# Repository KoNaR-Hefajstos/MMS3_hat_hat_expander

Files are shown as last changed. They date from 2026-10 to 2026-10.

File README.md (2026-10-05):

# Hat hat expander

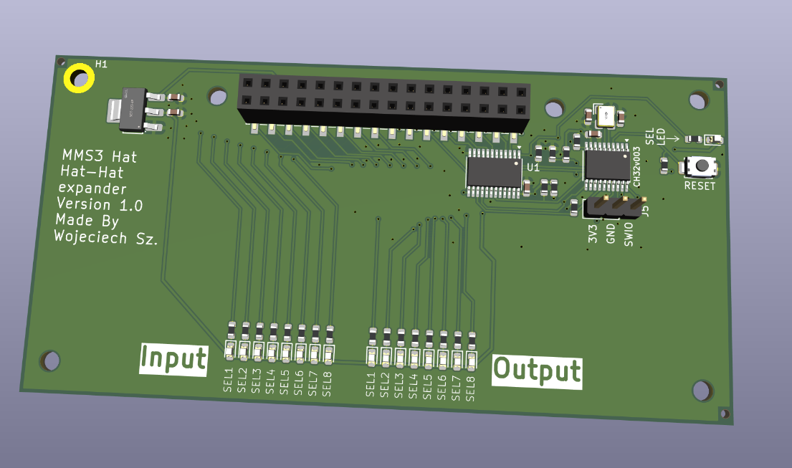
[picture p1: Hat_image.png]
zdjęcie hata


## Sekcja 0: Jak szybko, dobrze i tanio zrobić hata z dokumentacją

Szybka lista punkcików to wyklepania zanim hat magicznie się zrobi

1. **Sprawdź istniejące projekty:** Zobacz czy nie ma już jakiegoś hata który robi co potrzebujesz. Zobacz w forkach i poszukaj na githubie po hashtag'ach, jeśli nie to
2. **Utwórz Fork:** Kliknij przycisk **Fork** w prawym górnym rogu tego repozytorium.

1. **Konfiguracja repozytorium:** Daj mu adekwatną nazwe, i z'clone'uj forka do siebie na pc
2. **Zasady projektowania:**
   * Dokładniejsza dokumentacja znajduje się w Sekcji 2.
   * Do komunikacji możesz używać **wyłącznie** interfejsów: **I2C, SPI oraz UART**.
   * Modyfikuj połączeń złącza chainbus, bus switch'a i EEPROM'a
   * Nie modyfikuj zarysu płytki, otworów montażowych ani pozycji złączy ChainBus.
   * Możesz usunąć złącze XT60, jeśli Twój projekt go nie wymaga.

### Checklista przed zakończeniem projektu
Przed oznaczeniem projektu jako gotowy i wykonaniem ostatecznego commita, upewnij się, że zrealizowałeś poniższe punkty:

- [ ] Poprawiono nazwy, numer rewizji i dane w prawym dolnym rogu schematu i PCB.
- [ ] Dodano podpis autora/autorów oraz aktualny numer wersji na PCB.
- [ ] Zaktualizowano readme (usunąć tą sekcje)
- [ ] Zaktualizowano opis repo żeby opisywał krótko co robi PCB i jakie ma arkusze hierarchiczne do użycia w nowych hat'ach
- [ ] Usunięto z repozytorium zdjęcia z template'a.
- [ ] Wybrano i zaktualizowano licencję projektu **Uwaga: Wstpęnie już są użyte licencje**.
- [ ] Wygenerowano pliki produkcyjne Gerber
- [ ] Zrobiono commit'a i push'a

### Licencja
Co do licencji, wstępnie jest użyta
* Dla template'a - CC0 1.0 Universal  -> Róbcie co chcecie: Zmieniajce, usuńcie mój podpis, zróbcie closed source. Mi jest to obojętne
* PCB - CERN-OHL-W -> Ktoś może to modyfikować i sprzedać, ale musi zostawić projekt open source i ciebie jako twórce
* Software - MIT License -> Ktoś może to modyfikować i sprzedać, musi odnotować ciebie jako twórce ale **NIE MUSI ZOSTAWIĆ OPEN SOURCE**

Jeśli je modyfikujesz, pamiętaj usunać treści starych licencji

---

## Sekcja 1: Dokumentacja Hat'a

### Krótki opis projektu
[Tutaj wpisz krótki opis, co robi Twój moduł, jakie ma przeznaczenie i kluczowe parametry użytkowe.]

### Zgodność ze standardem ChainBus

* ✅ / ❌ Używa złącza ChainBus, nie zmienia jego miejsca ani pinoutu.
* ✅ / ❌ Używa wyłącznie interfejsów I2C, SPI lub UART i nie inicjuje samodzielnie nowych transmisji (Nie jest master'em I2C albo SPI).
* ✅ / ❌ Spełnia wymagania mechaniczne standardu (wymiary PCB, rozstaw otworów).
* ✅ / ❌ Pobiera maksymalny prąd zgodny z ilością na jednego hat'a
* ✅ / ❌ Obsługuje napięcie wejściowe BRD_VIN do wartości 48V.
<!-- Usuń odpowiednie emoji. Wszystkie powinny być na zielono. Jeśli z czymś nie jest zgodny to napisz w jaki sposób -->

### Komunikacja i adresowanie

#### Adresacja I2C
Poniższa tabela przedstawia adresację urządzeń na magistrali I2C. Wszystkie adresy podane są w formacie 7-bitowym.

| Układ (IC) | Funkcja |  Address |
| :--- | :--- | :---: |
| **JP3721** | Sterownik piekarnika | `1010000b` |
| **PCAL9535A** | Ekspander GPIO (Dioda LED, Krańcówki) | `0100000b` |
| **TMP102** | Czujnik temperatury | `1001000b` |

#### Magistrala SPI
Urządzenia SPI podłączone są bezpośrednio do magistrali systemowej bez użycia dodatkowych multiplekserów.

| Układ (IC)  | Funkcja | chainbus/multiplexer |
| :--- | :--- | :---: |
| **TMC5160** | Sterownik silnika krokowego | `chainbus` |

#### Magistrala UART
Komunikacja szeregowa UART realizowana jest w sposób bezpośredni z układem docelowym.

| Układ (IC) | Funkcja | chainbus/multiplexer |
| :--- | :--- | :---: |
| **ESP32-C3** | Adapter WI-FI | `chainbus` |

### Pinout złączy

| Jn | Co | Jaki pin co robi |
| :----- | :--- | :--- |
| **J1** | Zasilanie zewnętrzne silników | Pin 1: VIN (zasilanie dodatnie)<br>Pin 2: GND (masa zasilania) |
| **J2** | Wyjście faz silnika krokowego | Pin 1: Faza A1<br>Pin 2: Faza A2<br>Pin 3: Faza B1<br>Pin 4: Faza B2 |
| **J3** | Wejście czujnika krańcowego (Limit Switch) | Pin 1: Sygnał wejściowy (z rezystorem Pull-Up)<br>Pin 2: GND (masa)  |

### Konfiguracja układu (Zworki/Rezystory)

| Co | Jak podłączone | Efekt |
| :--- | :--- | :--- |
| **J1** | 1-2 zwarte | Silnik DC |
| | rozwarte | Silnik BLDC |
| **J2** | 1-2 zwarte | 3.3V out |
| | 2-3 zwarte | 5V out |
| **R1, R2, R3** | Wlutowany R1 | 3.3V out |
| | Wlutowany R2 | 5V out |
| | Wlutowany R3 | VIN out |

### Szczegółowy opis techniczny
[Tutaj umieść opis działania układu, parametry maksymalne etc]

### Gotowe arkusze hierarchiczne
W projekcie zaprojektowano/użyto następujących arkuszy hierarchicznych:
* [Nazwa arkusza 1] – [Krótki opis funkcjonalności, np. Zasilacz impulsowy 5V] - [ oryginalny/ wzięty z hata XXX]
* [Nazwa arkusza 2] – [Krótki opis] - [ -||- ]

---

## Sekcja 2: Specyfikacja standardu ChainBus

### Architektura i łączenie modułów
Standard ChainBus umożliwia modułowe łączenie hatów. Na jednym MMS3 można zamontować pionowo **do 8 hat'ów**. Połączenie realizowane jest poprzez wpięcie złącza męskiego kolejnego hat'a w złącze żeńskie poprzedniego

### Komunikacja i sterowanie
Magistrala ChainBus jest w pełni cyfrowa. Płyta główna nie steruje bezpośrednio sygnałami ogólnego przeznaczenia (GPIO) na poszczególnych hat'ach. Wszelkie operacje (np. obsługa diod LED, odczyt krańcówek, generowanie sygnałów PWM) muszą być realizowane przez dedykowane układy scalone (np. ekspandery portów, sterowniki) komunikujące się przez interfejsy systemowe.

*Przykład:*
`MCU` $\rightarrow$ `Expander GPIO po I2C` $\rightarrow$ `Dioda LED`

Wybór aktywnego modułu realizowany jest przez układ przełącznika magistrali (bus switch) na płycie głównej. Dzięki temu linie I2C, SPI i UART są niezależne dla każdego hat'a (brak konfliktów adresów I2C między różnymi hatami).
* **Identyfikacja:** Każdy moduł powinien posiadać pamięć EEPROM na magistrali I2C w celu identyfikacji płyty przez system - układ M24C64-W skonfigurowany na adres `1010000` przy liniach adresowych A0, A1, A2 zwartych do masy.

### Zasilanie
Złącze ChainBus dostarcza następujące linie zasilania:

| Magistrala zasilania | Napięcie znamionowe | Maksymalny prąd (łączny dla 8 hatów) | Szacowany prąd na jeden hat |
| :--- | :---: | :---: | :---: |
| **5V** | 5.0 V | 1.0 A | 125 mA |
| **12V stby** | 12.0 V | 0.5 A | 65 mA |
| **BRD_VIN** | 12.0 V – 48.0 V | 1.5 A | 185 mA |

*   Komponenty podłączone do linii `BRD_VIN` muszą być przystosowane do pracy z napięciem od 12V do **48 V**.
*   W przypadku zapotrzebowania na wyższą moc, dopuszczalne jest zastosowanie dodatkowego złącza zasilania XT60 (obciążalność do ok. 60 A).

### Wymagania mechaniczne i złącza
* **Wymiary PCB:** Niedozwolona jest zmiana obrysu płytki oraz położenia otworów montażowych, aby zachować kompatybilność mechaniczną.
* **Pozycjonowanie złączy ChainBus:** Położenie złącza standardu 2x16 SMD (raster 2.54 mm) musi być zgodne z szablonem. Złącze żeńskie montowane jest na stronie FRONT, natomiast złącze męskie na stronie BACK.
* **Interfejsy zewnętrzne:** Złącza wejścia/wyjścia (domyślnie standard JST-XH 2.5 mm o obciążalności do 3 A) oraz opcjonalne złącze XT60 powinny być umieszczone przy dolnej krawędzi płytki. Elementy regulacyjne i sygnalizacyjne (potencjometry, przełączniki, diody LED) należy lokalizować przy prawej krawędzi płytki.
* **Komponenty** Wszystkie komponenty powinny być na stronie front płytki żeby nie haczyły o elementy ze wcześniejszego hat'a

---

## Sekcja 3: Licencja, linki i tagi

### Licencjonowanie projektu

*   **PCB:** [CERN-OHL-W](https://ohwr.org/project/cernohl/wikis/Documents/CERN-OHL-version-2) - Umożliwia modyfikacje i sprzedaż, ale musi pozostawić oryginalnego autora i zmiany muszą być open source
*   **Software:** [MIT License](https://opensource.org/licenses/MIT) - Umożliwia modyfikacje i sprzedaż, ale musi pozostawić oryginalnego autora. Zmiany **nie muszą być open source**

[Template](https://github.com/KoNaR-Hefajstos/MMS3_hat_templates/) jest na licencji CC0 1.0 Universal. **Reszta projektu nie jest na tej licencji**
### Tagi projektu
#chainbus #MMS3 #ModuCard

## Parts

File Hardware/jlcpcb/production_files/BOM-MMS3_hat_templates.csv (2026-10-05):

Comment | Designator | Footprint | LCSC | Quantity
100nF | C1,C3 | C_0603 | C14663 | 2
10kΩ | R1,R10,R2,R3,R4,R6,R9 | R_0603 | C25804 | 7
10uF | C16,C18 | C_0603 | C19702 | 2
12pF | C4,C5 | C_0603 | C38523 | 2
1kΩ | R12,R15,R16,R17,R18,R19,R20,R21,R22,R23,R24,R25,R26,R27,R28,R29,R7 | R_0603 | C21190 | 17
AMS1117 | U4 | SOT-223-3_L6.5-W3.4-P2.30-LS7.0-BR | C6186 | 1
Red | D10,D11,D12,D13,D14,D15,D16,D17,D18,D2,D3,D4,D5,D6,D7,D8,D9 | D_0603 | C2286 | 17
SN74CB3Q3384APW | U1 | TSSOP-24_4.4x7.8mm_P0.65mm | C469874 | 1
Tactile Button, 160gf | S1 | SW_TS-1088-AR02016 | C720477 | 1
X322525MOB4SI | X1 | OSC-SMD_4P-L3.2-W2.5-BL | C9006 | 1
CH32V003FxPx | U3 | TSSOP-20_4.4x6.5mm_P0.65mm |  | 1
Chainbus Out | J2 | PinSocket_2x16_P2.54mm_Vertical_SMD |  | 1
~ | H8 | Hole_Tooling_JLCPCB |  | 1
~ | H7 | Hole_Tooling_JLCPCB |  | 1
~ | H9 | Hole_Tooling_JLCPCB |  | 1
Program | J5 | PinHeader_1x03_P2.54mm_Vertical |  | 1
Chainbus in | J1 | PinHeader_2x16_P2.54mm_Vertical_SMD |  | 1

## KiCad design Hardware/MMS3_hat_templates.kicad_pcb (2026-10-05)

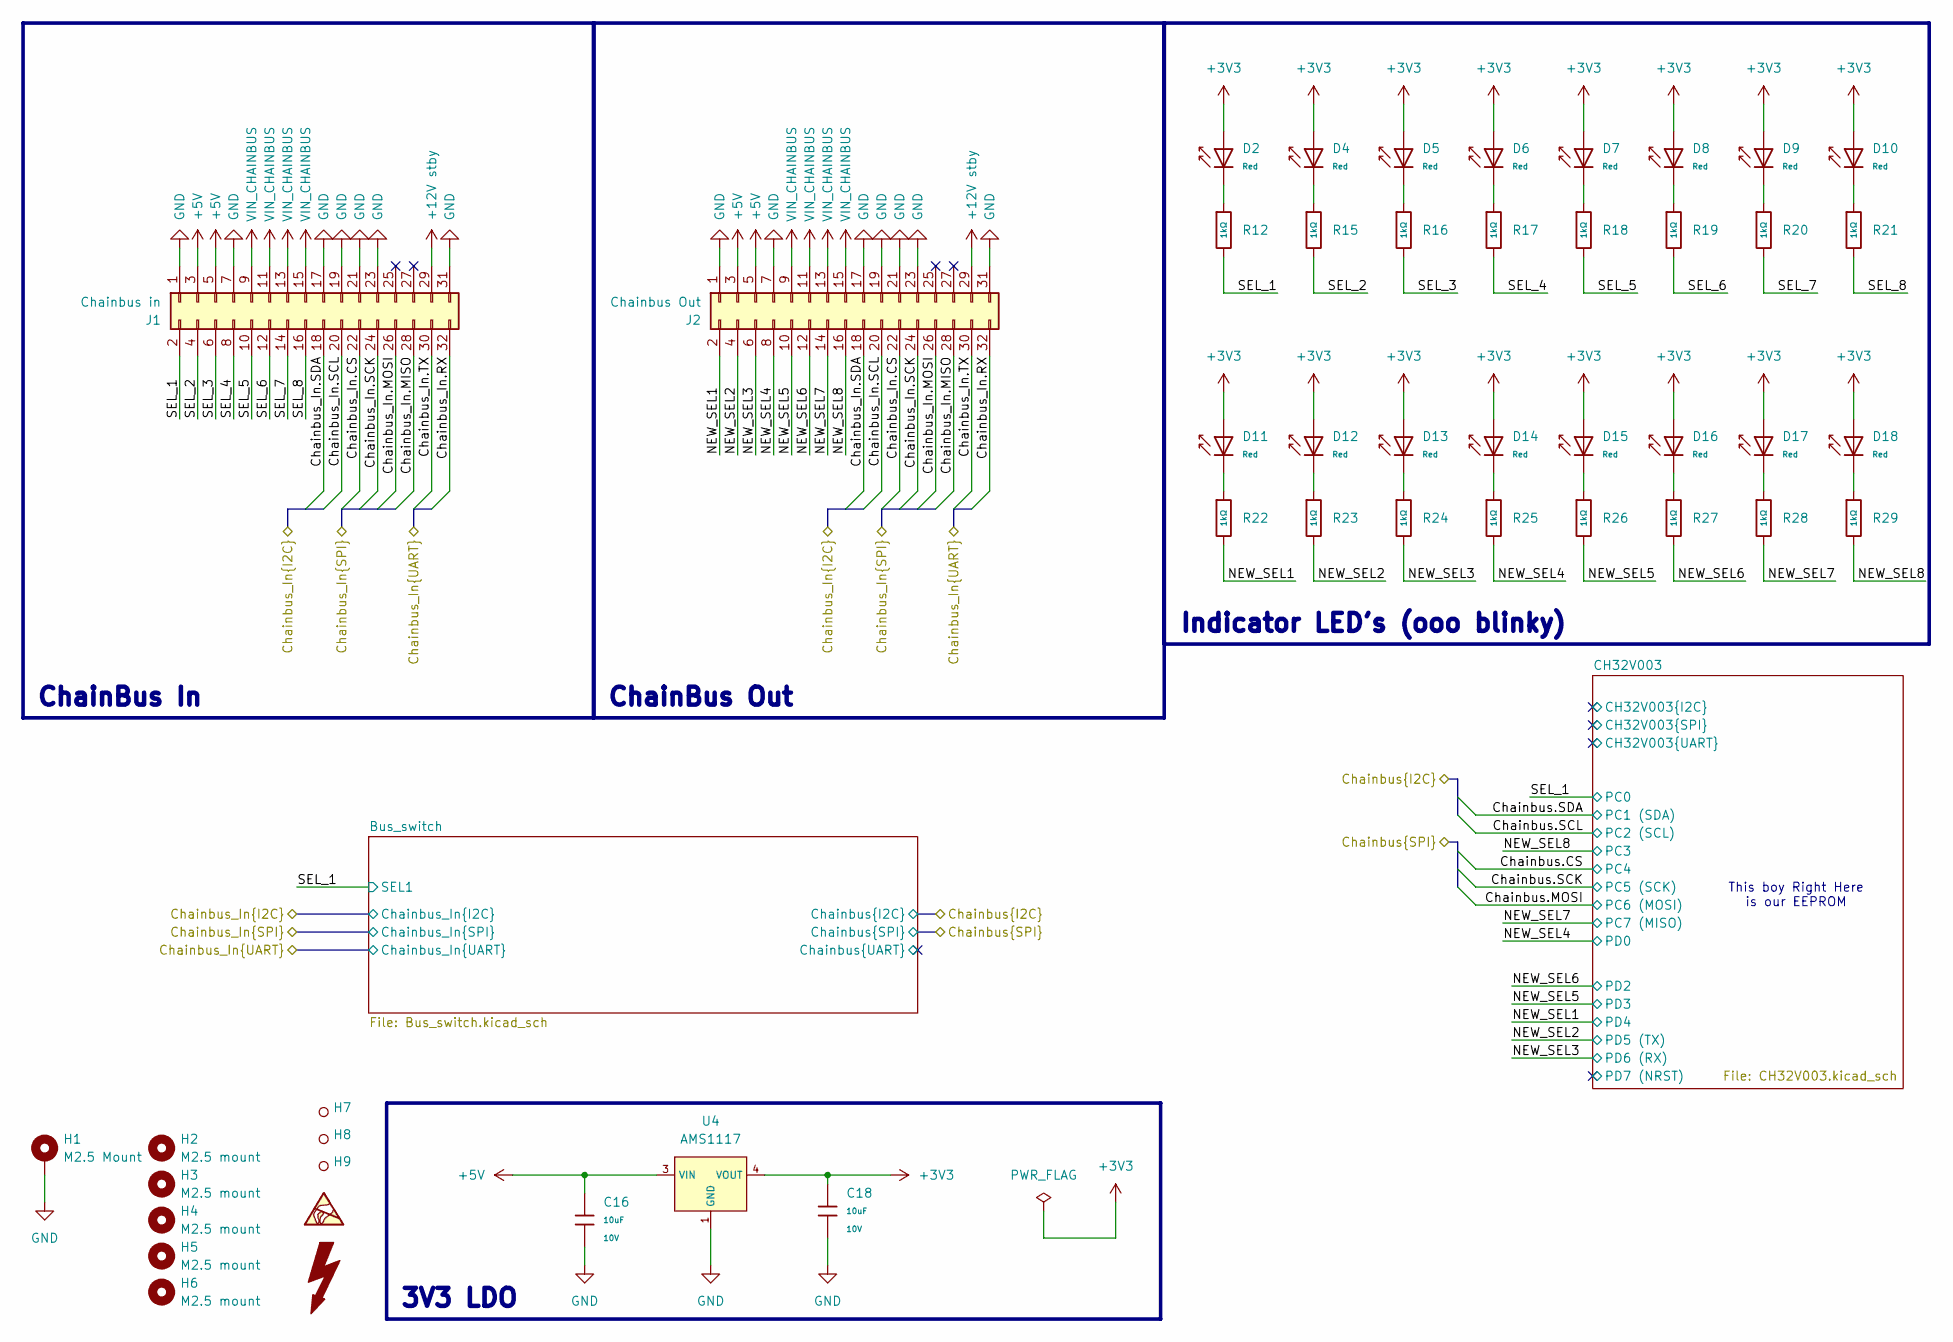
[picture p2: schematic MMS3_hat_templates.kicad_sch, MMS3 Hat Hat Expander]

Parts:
C16, C18: 10uF; C_0603; Voltage Rated 10V; Tolerance ±10%; Part CL10A106KP8NNNC; LCSC C19702
D2, D4, D5, D6, D7, D8, D9, D10, D11, D12, D13, D14, D15, D16, D17, D18: Red; D_0603; Part KT-0603R; LCSC C2286
H1: M2.5 Mount; MountingHole_2.7mm_M2.5_DIN965_Pad_TopOnly
H2, H3, H4, H5, H6: M2.5 mount; MountingHole_2.7mm_M2.5
H7, H8, H9: Hole_Tooling_JLCPCB
J1: Chainbus in; PinHeader_2x16_P2.54mm_Vertical_SMD
J2: Chainbus Out; PinSocket_2x16_P2.54mm_Vertical_SMD
R12, R15, R16, R17, R18, R19, R20, R21, R22, R23, R24, R25, R26, R27, R28, R29: 1kΩ; R_0603; Overload Voltage (Max) 75V; Tolerance ±1%; Part 0603WAF1001T5E; LCSC C21190
U4: AMS1117; SOT-223-3_L6.5-W3.4-P2.30-LS7.0-BR; Output Voltage 3.3V; Dropout Voltage 1.3V@(800mA); Part AMS1117-3.3; LCSC C6186

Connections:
+3V3: C18.1, D2.2, D4.2, D5.2, D6.2, D7.2, D8.2, D9.2, D10.2, D11.2, D12.2, D13.2, D14.2, D15.2, D16.2, D17.2, D18.2, U4.2 (VOUT), U4.4 (VOUT); also elsewhere on the board
+5V: C16.1, J1.3, J1.5, J2.3, J2.5, U4.3 (VIN)
+12V stby: J1.29, J2.29
/Chainbus_In.CS: J1.22, J2.22; also elsewhere on the board
/Chainbus_In.MISO: J1.28, J2.28; also elsewhere on the board
/Chainbus_In.MOSI: J1.26, J2.26; also elsewhere on the board
/Chainbus_In.RX: J1.32, J2.32; also elsewhere on the board
/Chainbus_In.SCK: J1.24, J2.24; also elsewhere on the board
/Chainbus_In.SCL: J1.20, J2.20; also elsewhere on the board
/Chainbus_In.SDA: J1.18, J2.18; also elsewhere on the board
/Chainbus_In.TX: J1.30, J2.30; also elsewhere on the board
/NEW_SEL1: J2.2, R22.2; also elsewhere on the board
/NEW_SEL2: J2.4, R23.2; also elsewhere on the board
/NEW_SEL3: J2.6, R24.2; also elsewhere on the board
/NEW_SEL4: J2.8, R25.2; also elsewhere on the board
/NEW_SEL5: J2.10, R26.2; also elsewhere on the board
/NEW_SEL6: J2.12, R27.2; also elsewhere on the board
/NEW_SEL7: J2.14, R28.2; also elsewhere on the board
/NEW_SEL8: J2.16, R29.2; also elsewhere on the board
/SEL_1: J1.2, R12.2; also elsewhere on the board
/SEL_2: J1.4, R15.2
/SEL_3: J1.6, R16.2
/SEL_4: J1.8, R17.2
/SEL_5: J1.10, R18.2
/SEL_6: J1.12, R19.2
/SEL_7: J1.14, R20.2
/SEL_8: J1.16, R21.2
GND: C16.2, C18.2, H1.1 (1_1), J1.1, J1.7, J1.17, J1.19, J1.21, J1.23, J1.31, J2.1, J2.7, J2.17, J2.19, J2.21, J2.23, J2.31, U4.1 (GND); also elsewhere on the board
unnamed: D2.1, R12.1
unnamed: D4.1, R15.1
unnamed: D5.1, R16.1
unnamed: D6.1, R17.1
unnamed: D7.1, R18.1
unnamed: D8.1, R19.1
unnamed: D9.1, R20.1
unnamed: D10.1, R21.1
unnamed: D11.1, R22.1
unnamed: D12.1, R23.1
unnamed: D13.1, R24.1
unnamed: D14.1, R25.1
unnamed: D15.1, R26.1
unnamed: D16.1, R27.1
unnamed: D17.1, R28.1
unnamed: D18.1, R29.1
VIN_CHAINBUS: J1.9, J1.11, J1.13, J1.15, J2.9, J2.11, J2.13, J2.15

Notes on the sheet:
This boy Right Here is our EEPROM
ChainBus In
Indicator LED's (ooo blinky)
ChainBus Out
3V3 LDO

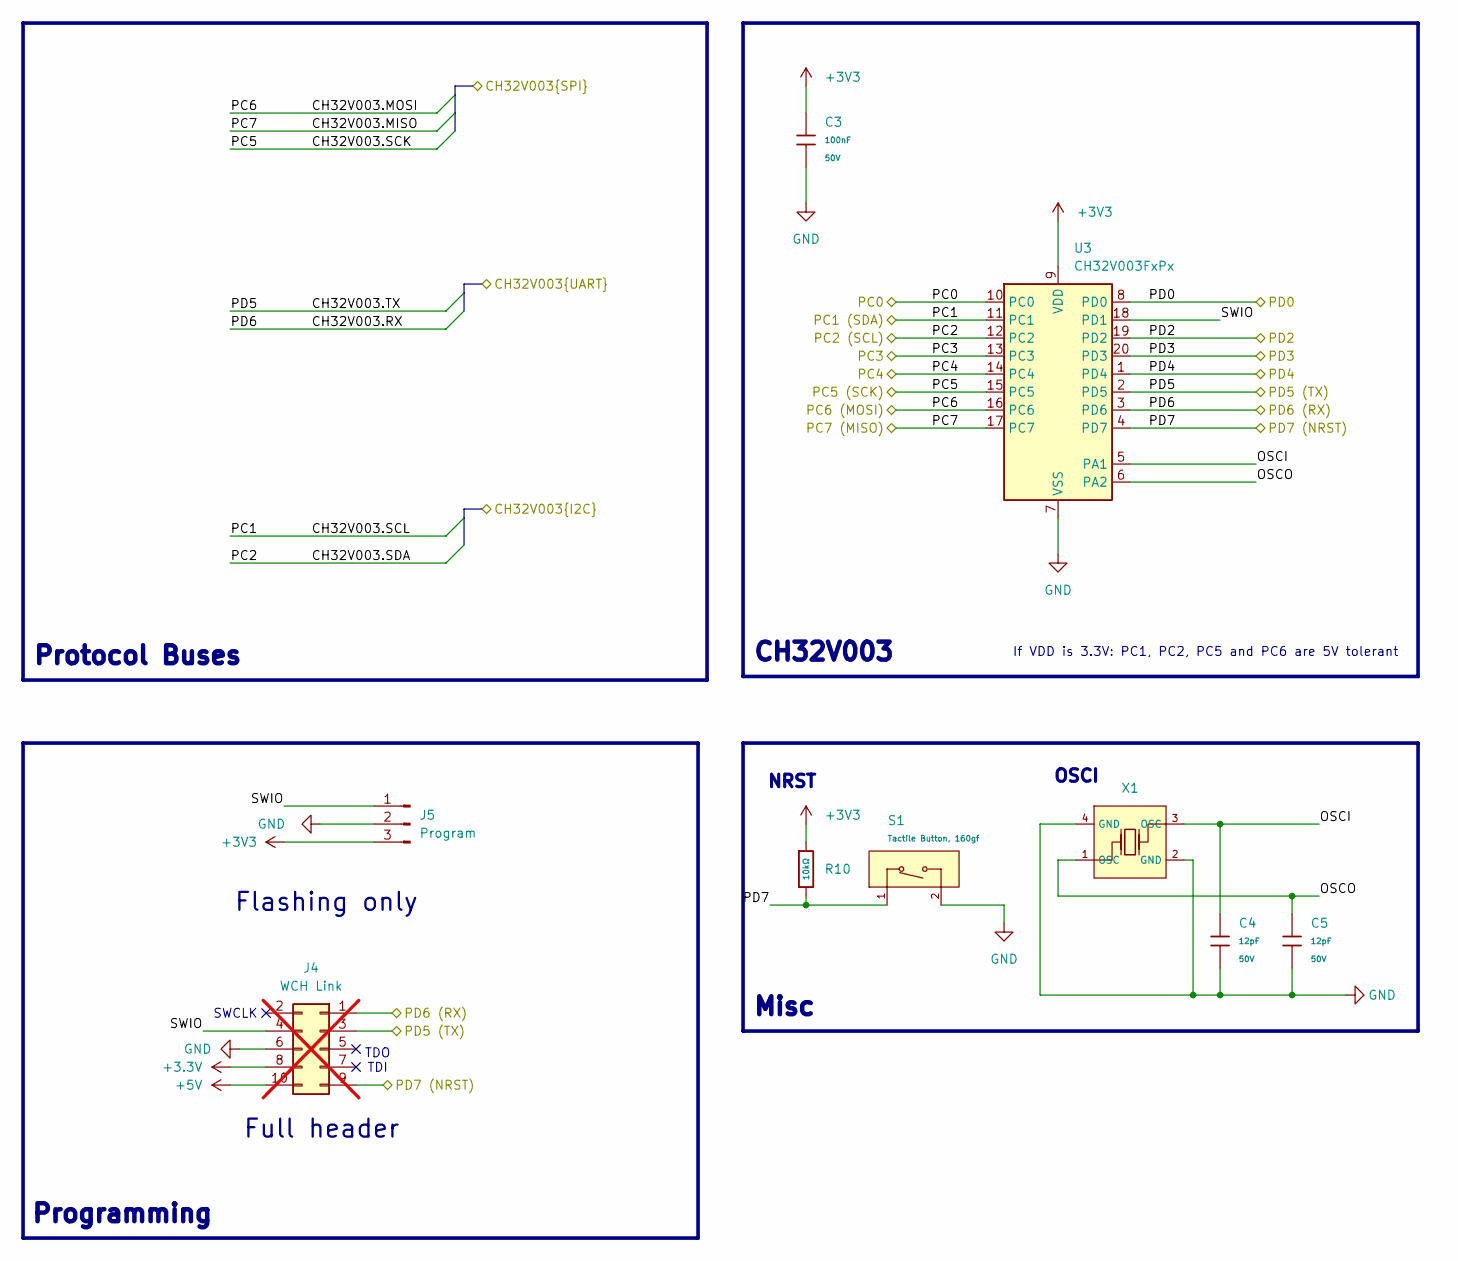
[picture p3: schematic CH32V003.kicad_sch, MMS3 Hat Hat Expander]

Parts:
C3: 100nF; C_0603; Voltage Rated 50V; Tolerance ±10%; Part CC0603KRX7R9BB104; LCSC C14663
C4, C5: 12pF; C_0603; Voltage Rated 50V; Tolerance ±5%; Part CL10C120JB8NNNC; LCSC C38523
J4: WCH Link; PinSocket_2x05_P2.54mm_Vertical; not fitted
J5: Program; PinHeader_1x03_P2.54mm_Vertical
R10: 10kΩ; R_0603; Overload Voltage (Max) 75V; Tolerance ±1%; Part 0603WAF1002T5E; LCSC C25804
S1: Tactile Button, 160gf; SW_TS-1088-AR02016; Voltage Rating (Dc) 12V; Part TS-1088-AR02016; LCSC C720477
U3: CH32V003FxPx; TSSOP-20_4.4x6.5mm_P0.65mm
X1: X322525MOB4SI; OSC-SMD_4P-L3.2-W2.5-BL; Frequency Tolerance ±10ppm; Part X322525MOB4SI; LCSC C9006

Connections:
+3V3: C3.1, J5.3, R10.1, U3.9 (VDD); also elsewhere on the board
/CH32V003/OSCI: C4.1, U3.5 (PA1), X1.3 (OSC)
/CH32V003/OSCO: C5.1, U3.6 (PA2), X1.1 (OSC)
/CH32V003/PD7: J4.9, R10.2, S1.1 (A), U3.4 (PD7)
/CH32V003/SWIO: J4.4, J5.1, U3.18 (PD1)
/Chainbus.CS: U3.14 (PC4); also elsewhere on the board
/Chainbus.MOSI: U3.16 (PC6); also elsewhere on the board
/Chainbus.SCK: U3.15 (PC5); also elsewhere on the board
/Chainbus.SCL: U3.12 (PC2); also elsewhere on the board
/Chainbus.SDA: U3.11 (PC1); also elsewhere on the board
/NEW_SEL1: U3.1 (PD4); also elsewhere on the board
/NEW_SEL2: J4.3, U3.2 (PD5); also elsewhere on the board
/NEW_SEL3: J4.1, U3.3 (PD6); also elsewhere on the board
/NEW_SEL4: U3.8 (PD0); also elsewhere on the board
/NEW_SEL5: U3.20 (PD3); also elsewhere on the board
/NEW_SEL6: U3.19 (PD2); also elsewhere on the board
/NEW_SEL7: U3.17 (PC7); also elsewhere on the board
/NEW_SEL8: U3.13 (PC3); also elsewhere on the board
/SEL_1: U3.10 (PC0); also elsewhere on the board
GND: C3.2, C4.2, C5.2, J4.6, J5.2, S1.2 (B), U3.7 (VSS), X1.2 (GND), X1.4 (GND); also elsewhere on the board

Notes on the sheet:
NRST
Full header
SWCLK
If VDD is 3.3V: PC1, PC2, PC5 and PC6 are 5V tolerant
CH32V003
Flashing only
OSCI
Protocol Buses
Misc
Programming
TDO TDI

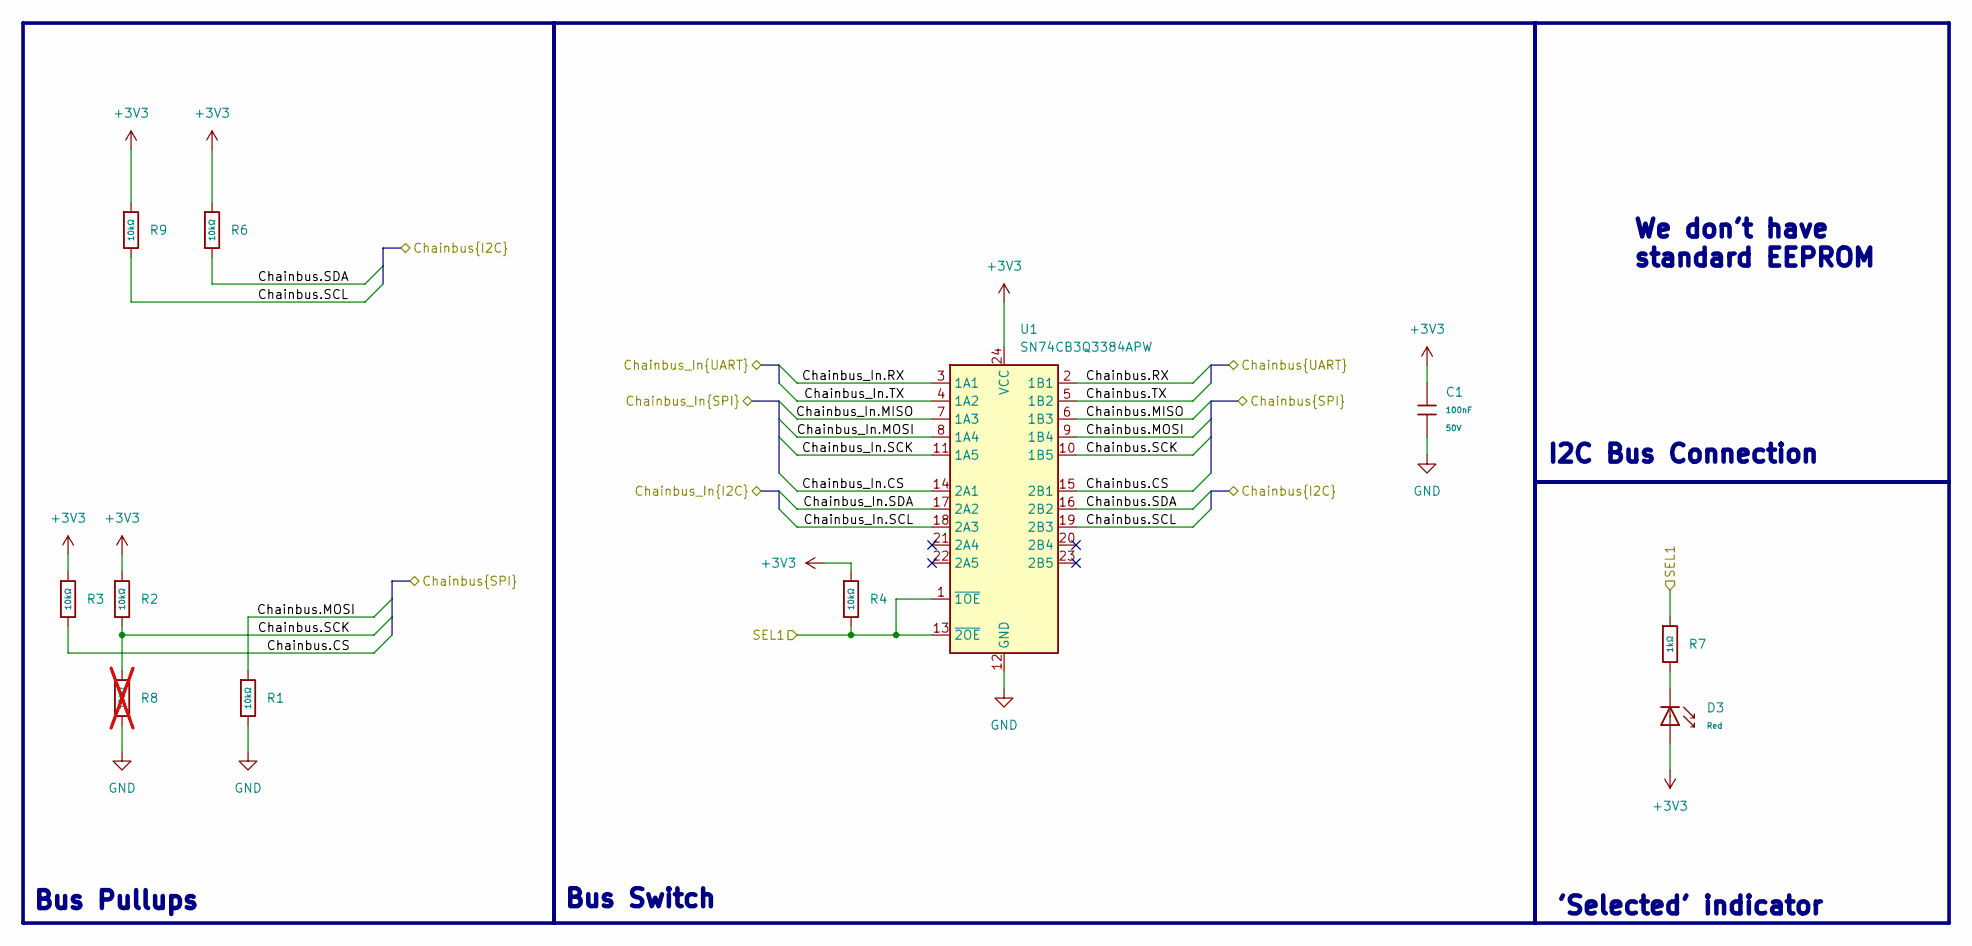
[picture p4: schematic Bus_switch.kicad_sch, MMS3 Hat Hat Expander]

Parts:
C1: 100nF; C_0603; Voltage Rated 50V; Tolerance ±10%; Part CC0603KRX7R9BB104; LCSC C14663
D3: Red; D_0603; Part KT-0603R; LCSC C2286
R1, R2, R3, R4, R6, R9: 10kΩ; R_0603; Overload Voltage (Max) 75V; Tolerance ±1%; Part 0603WAF1002T5E; LCSC C25804
R7: 1kΩ; R_0603; Overload Voltage (Max) 75V; Tolerance ±1%; Part 0603WAF1001T5E; LCSC C21190
R8: 10kΩ; R_0603; Overload Voltage (Max) 75V; Tolerance ±1%; Part 0603WAF1002T5E; LCSC C25804; not fitted
U1: SN74CB3Q3384APW; TSSOP-24_4.4x7.8mm_P0.65mm; LCSC C469874

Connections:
+3V3: C1.1, D3.2, R2.1, R3.1, R4.1, R6.1, R9.1, U1.24 (VCC); also elsewhere on the board
/Bus_switch/Chainbus.RX: U1.2 (1B1)
/Bus_switch/Chainbus.TX: U1.5 (1B2)
/Chainbus.CS: R3.2, U1.15 (2B1); also elsewhere on the board
/Chainbus.MISO: U1.6 (1B3)
/Chainbus.MOSI: R1.1, U1.9 (1B4); also elsewhere on the board
/Chainbus.SCK: R2.2, R8.1, U1.10 (1B5); also elsewhere on the board
/Chainbus.SCL: R9.2, U1.19 (2B3); also elsewhere on the board
/Chainbus.SDA: R6.2, U1.16 (2B2); also elsewhere on the board
/Chainbus_In.CS: U1.14 (2A1); also elsewhere on the board
/Chainbus_In.MISO: U1.7 (1A3); also elsewhere on the board
/Chainbus_In.MOSI: U1.8 (1A4); also elsewhere on the board
/Chainbus_In.RX: U1.3 (1A1); also elsewhere on the board
/Chainbus_In.SCK: U1.11 (1A5); also elsewhere on the board
/Chainbus_In.SCL: U1.18 (2A3); also elsewhere on the board
/Chainbus_In.SDA: U1.17 (2A2); also elsewhere on the board
/Chainbus_In.TX: U1.4 (1A2); also elsewhere on the board
/SEL_1: R4.2, R7.1, U1.1 (~1OE), U1.13 (~2OE); also elsewhere on the board
GND: C1.2, R1.2, R8.2, U1.12 (GND); also elsewhere on the board
unnamed: D3.1, R7.2

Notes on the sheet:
Bus Switch
'Selected' indicator
Bus Pullups
We don't have standard EEPROM
I2C Bus Connection

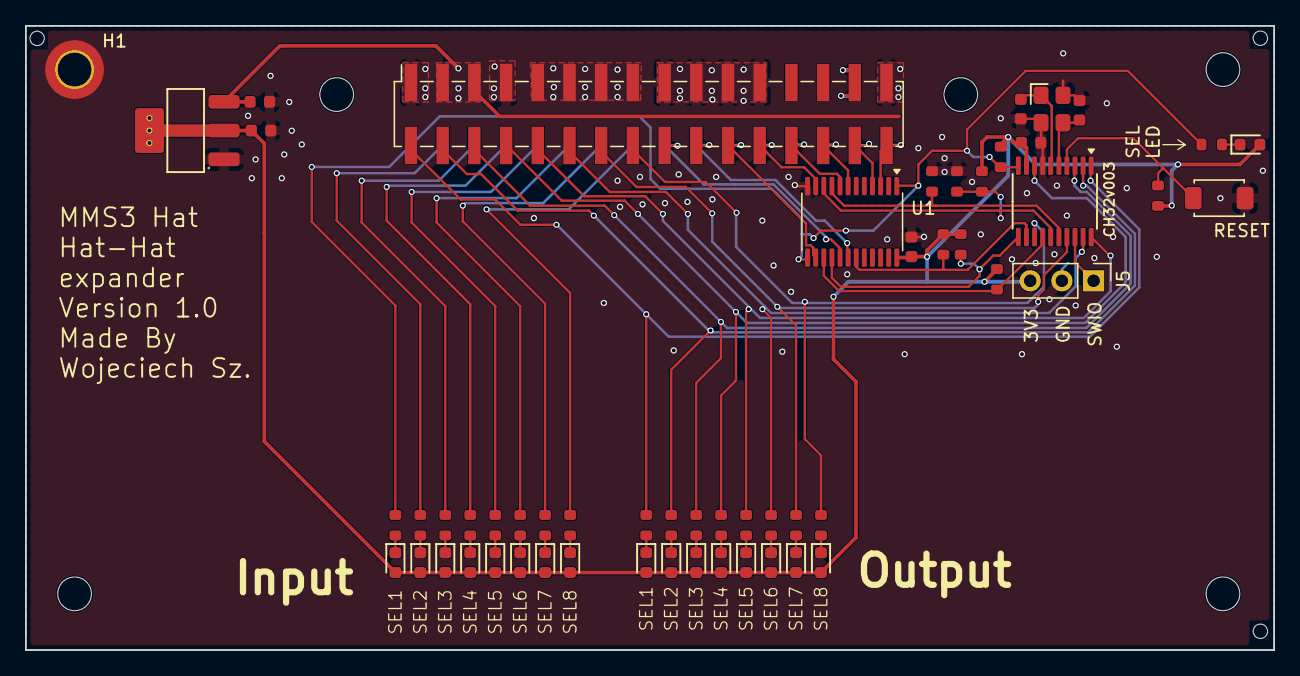
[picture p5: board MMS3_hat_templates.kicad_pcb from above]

Board: 2 copper layers, 100.0 x 50.0 mm, 65 parts (1 on the bottom side), 55 nets.

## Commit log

2026-07-15 made pcb
    [BOM-MMS3_hat_templates.csv, Bus_switch.kicad_sch, CH32V003.kicad_sch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]
2026-10-05 added photo
    [BOM-MMS3_hat_templates.csv, Bus_switch.kicad_sch, CH32V003.kicad_sch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]
